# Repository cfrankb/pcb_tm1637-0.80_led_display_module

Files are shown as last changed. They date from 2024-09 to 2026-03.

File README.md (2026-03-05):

# TM1637 7-Segments 0.80" LED Module

## Introduction

This is a pcb design for the 0.80" LED 7-Segments Display Module. The board is pin compatible with the standard 0.56" LED 7-Segments Display Module

This hardware module is supported by a native C++ driver implementation (linked below), demonstrating a full-stack IoT approach from physical PCB to firmware abstraction.

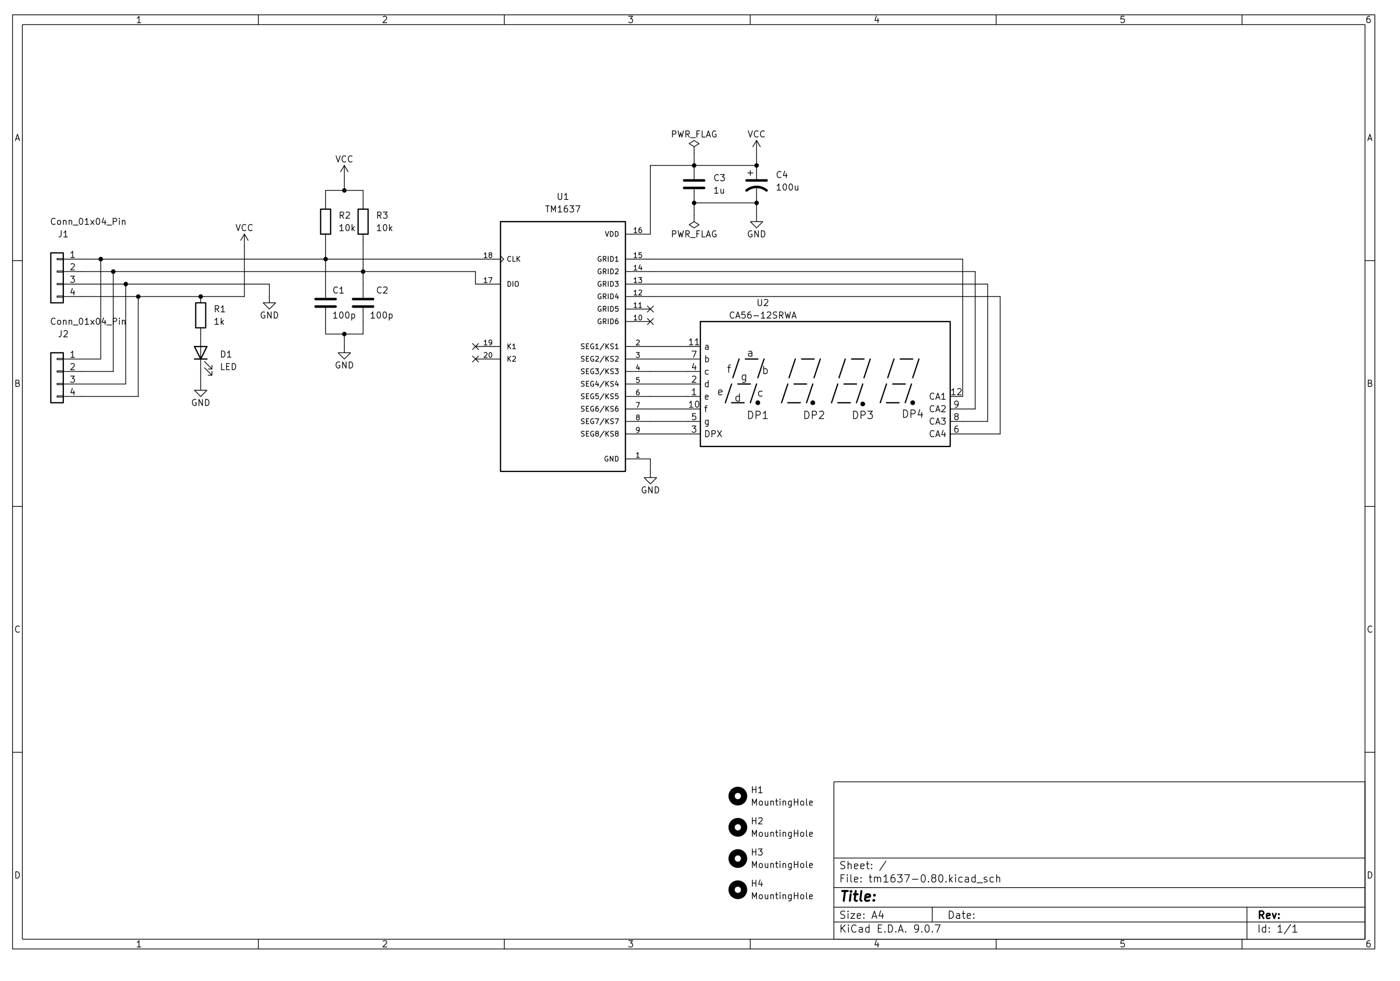
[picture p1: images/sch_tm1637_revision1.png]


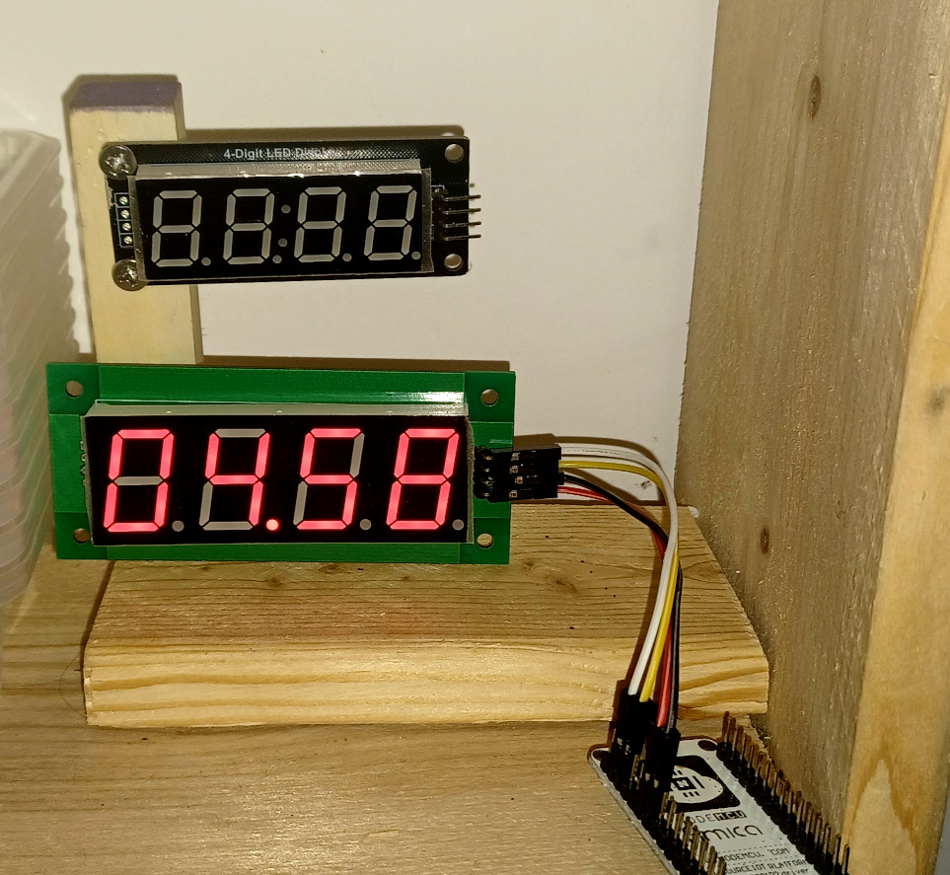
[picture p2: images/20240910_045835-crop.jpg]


Reflowed using a controlled hotplate process with lead-free solder paste (SAC305). The screen was hand soldered using a standard soldering iron. The screen can be attached directly or socketed.

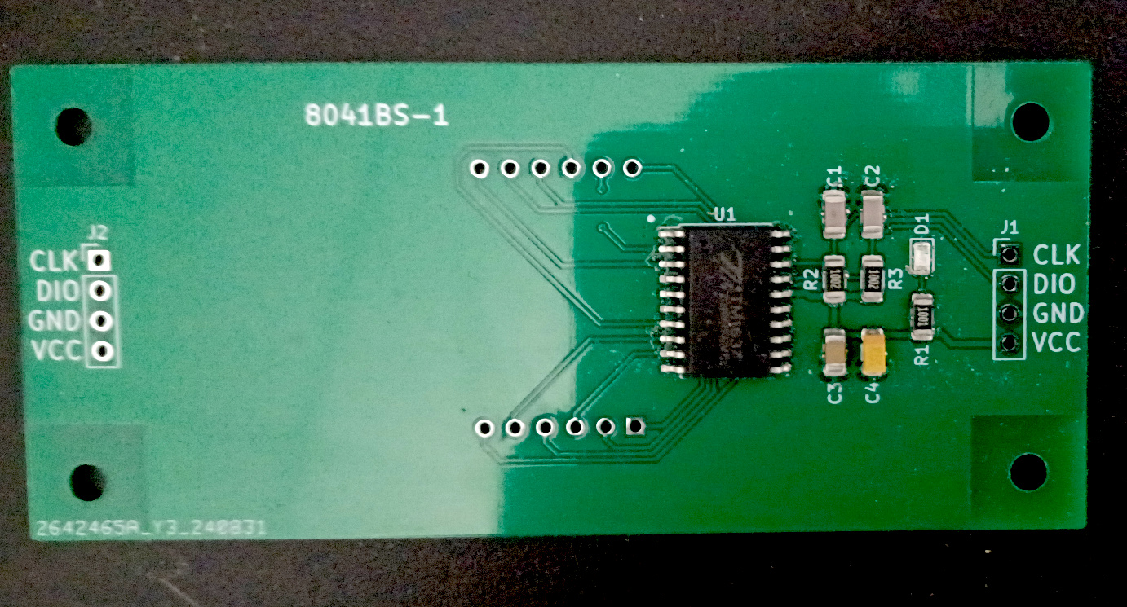
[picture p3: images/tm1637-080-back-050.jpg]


## Features

 * Display numbers
 * Display raw segment data
 * Scrolling text
 * Simplified interface
 * C++ Implementation

ESP32 driver for this board [GitHub cfrankb/esp32-tm1637plus-cpp](https://github.com/cfrankb/esp32-tm1637plus-cpp).

## 0.80" 7-Segments LED Displays Tested

| Part # | Size  | Pins |
| --- | ----- | ---- |
| 8041BS-1  | 0.80" | 12 |
| 8401BS-1F | 0.80" | 14*  |

\* Requires a 2.54mm female socket.

## Part List

| | Part # | REF# | Package |
| --- | --- | --- | --- |
| 2x  | 100p C | C1, C2 | 1206 |
| 1x  | 1k Resistor | R1 | 1206 |
| 2x  | 10k Resistor | R2, R3 | 1206 |
| 1x  | Green Led | D1 | 0805 |
| 1x  | 1u C | C3 | 1206 |
| 1x  | 100u Tantalum C | C4 | 3216 |
| 1x  | TM1637 | U1 | SOP-20 |
| 1x  | 0.80" LED Display | U2 | see above |

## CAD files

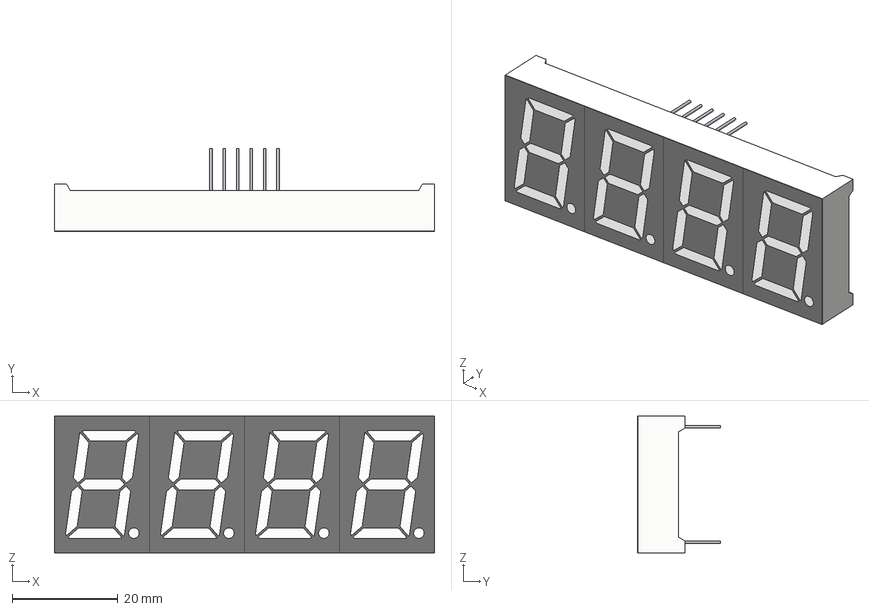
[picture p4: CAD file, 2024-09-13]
revision1/8041AS-0_8inch.stp
71.9 x 15.8 x 25.9 mm
Digit face x 4
Casing
Pins

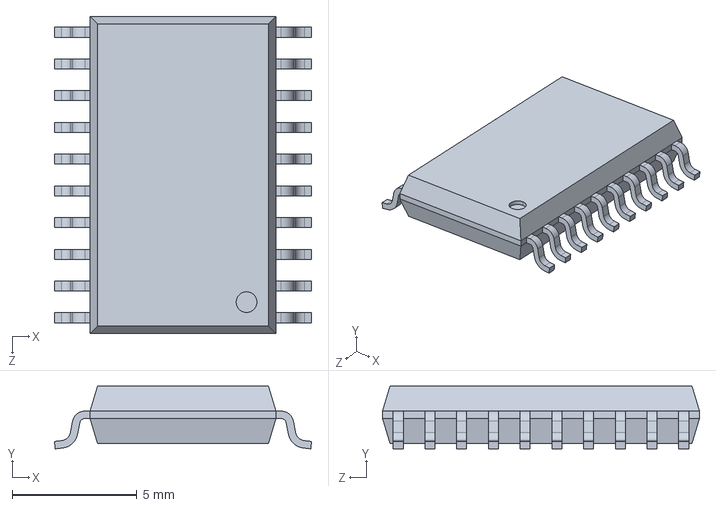
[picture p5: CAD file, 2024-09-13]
revision1/SOP-20-1.stp
10.3 x 2.52 x 12.7 mm

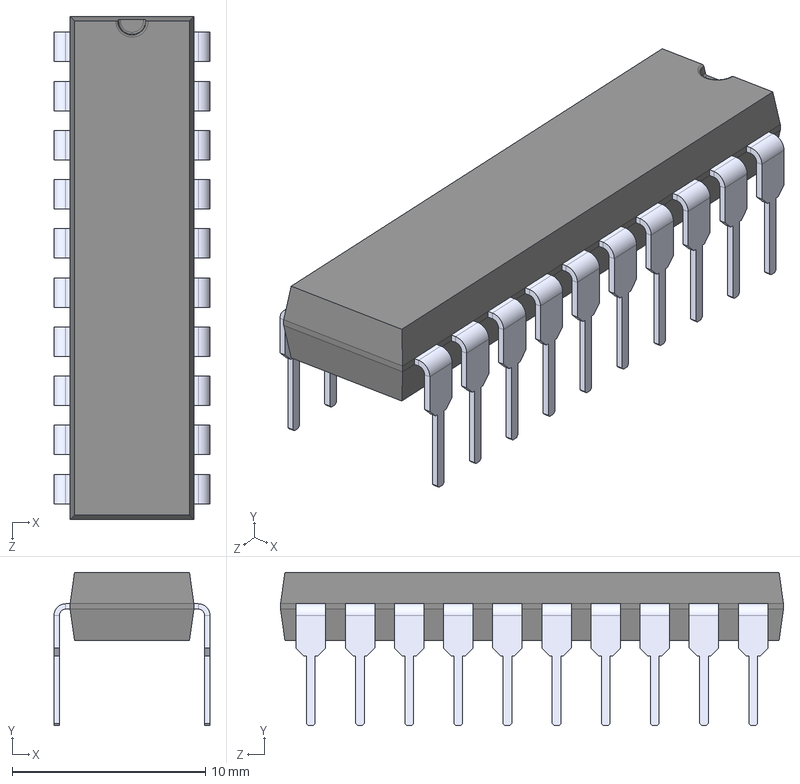
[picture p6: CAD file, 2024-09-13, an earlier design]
revision0/custom_parts/TM1637.step
8.06 x 7.91 x 26.0 mm

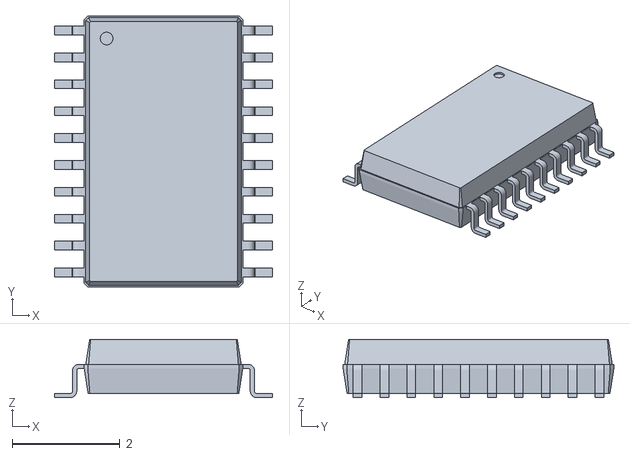
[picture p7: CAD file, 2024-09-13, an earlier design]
revision0/custom_parts/SOIC-20W_7.5x12.8mm_P1.27mm.wrl.stl
4.06 x 5.04 x 1.08

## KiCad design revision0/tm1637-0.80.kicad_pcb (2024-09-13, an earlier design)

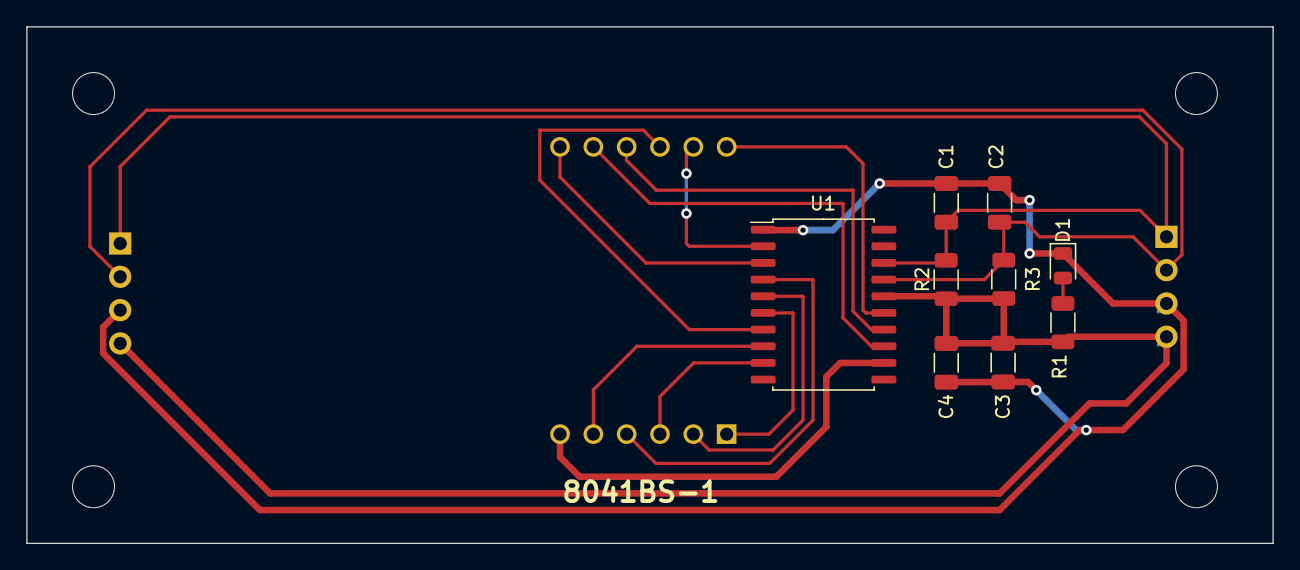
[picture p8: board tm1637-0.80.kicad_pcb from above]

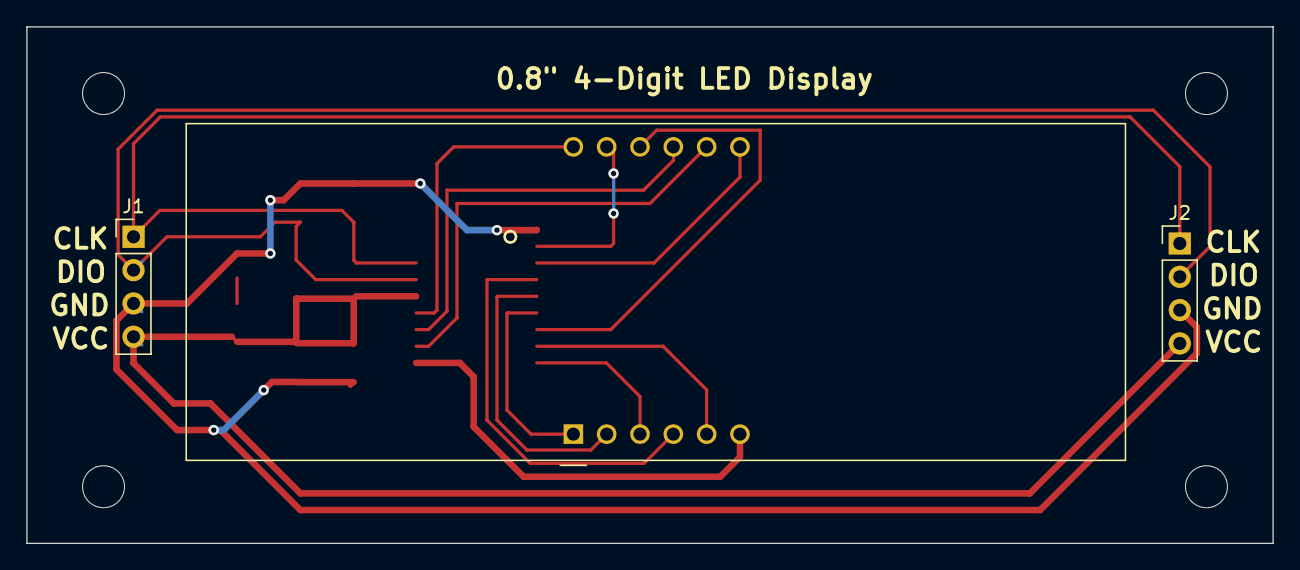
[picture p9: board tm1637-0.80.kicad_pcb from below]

Board: 2 copper layers, 95.0 x 39.4 mm, 16 parts (7 on the bottom side), 17 nets.

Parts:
C1, C2: 100p; C_1206_3216Metric
C3: 1u; C_1206_3216Metric
C4: 100u; C_1206_3216Metric
D1: LED; LED_0805_2012Metric
H1, H2, H3, H4: MountingHole; MountingHole_3.2mm_M3
J1, J2: Conn_01x04; PinHeader_1x04_P2.54mm_Vertical
R1: 1k; R_1206_3216Metric
R2, R3: 10k; R_1206_3216Metric
U1: TM1637; SOP-20_7.5x12.8mm_P1.27mm
U2: CA56-12SRWA; 8041AS

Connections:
GNDREF: C1.2, C2.2, C3.2, C4.2, D1.1 (K), J1.3, J2.3, U1.1 (GND)
unnamed: D1.2 (A), R1.2
unnamed: C1.1, J1.1, J2.1, R2.2, U1.18 (CLK)
unnamed: C2.1, J1.2, J2.2, R3.2, U1.17 (DIO)
unnamed: U1.15 (GRID1), U2.12 (CA1)
unnamed: U1.14 (GRID2), U2.9 (CA2)
unnamed: U1.13 (GRID3), U2.8 (CA3)
unnamed: U1.12 (GRID4), U2.6 (CA4)
unnamed: U1.2 (SEG1/KS1), U2.11 (a)
unnamed: U1.3 (SEG2/KS2), U2.7 (b)
unnamed: U1.4 (SEG3/KS3), U2.4 (c)
unnamed: U1.5 (SEG4/KS4), U2.2 (d)
unnamed: U1.6 (SEG5/KS5), U2.1 (e)
unnamed: U1.7 (SEG6/KS6), U2.10 (f)
unnamed: U1.8 (SEG7/KS7), U2.5 (g)
unnamed: U1.9 (SEG8/KS8), U2.3 (DPX)
VCC: C3.1, C4.1, J1.4, J2.4, R1.1, R2.1, R3.1, U1.16 (VDD)
